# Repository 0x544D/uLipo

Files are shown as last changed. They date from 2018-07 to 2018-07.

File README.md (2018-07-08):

# uLipo
LiPo based universal Microcontroller board featuring an ATMega328p

# Features
* ATMega328p based microcontroller platform for various projects
* LiPo charging upto 500 mA/h using MCP73833
* Step-up voltage regulation LiPo voltage -> 5V
* USB-UART bridge for communication with PC over USB using COM port (CH340G)
* Arduino Nano compatible pinout

# Shields
* Shield Template can be used to create stackable shields.
* Shield for LED application available (WS2812B)

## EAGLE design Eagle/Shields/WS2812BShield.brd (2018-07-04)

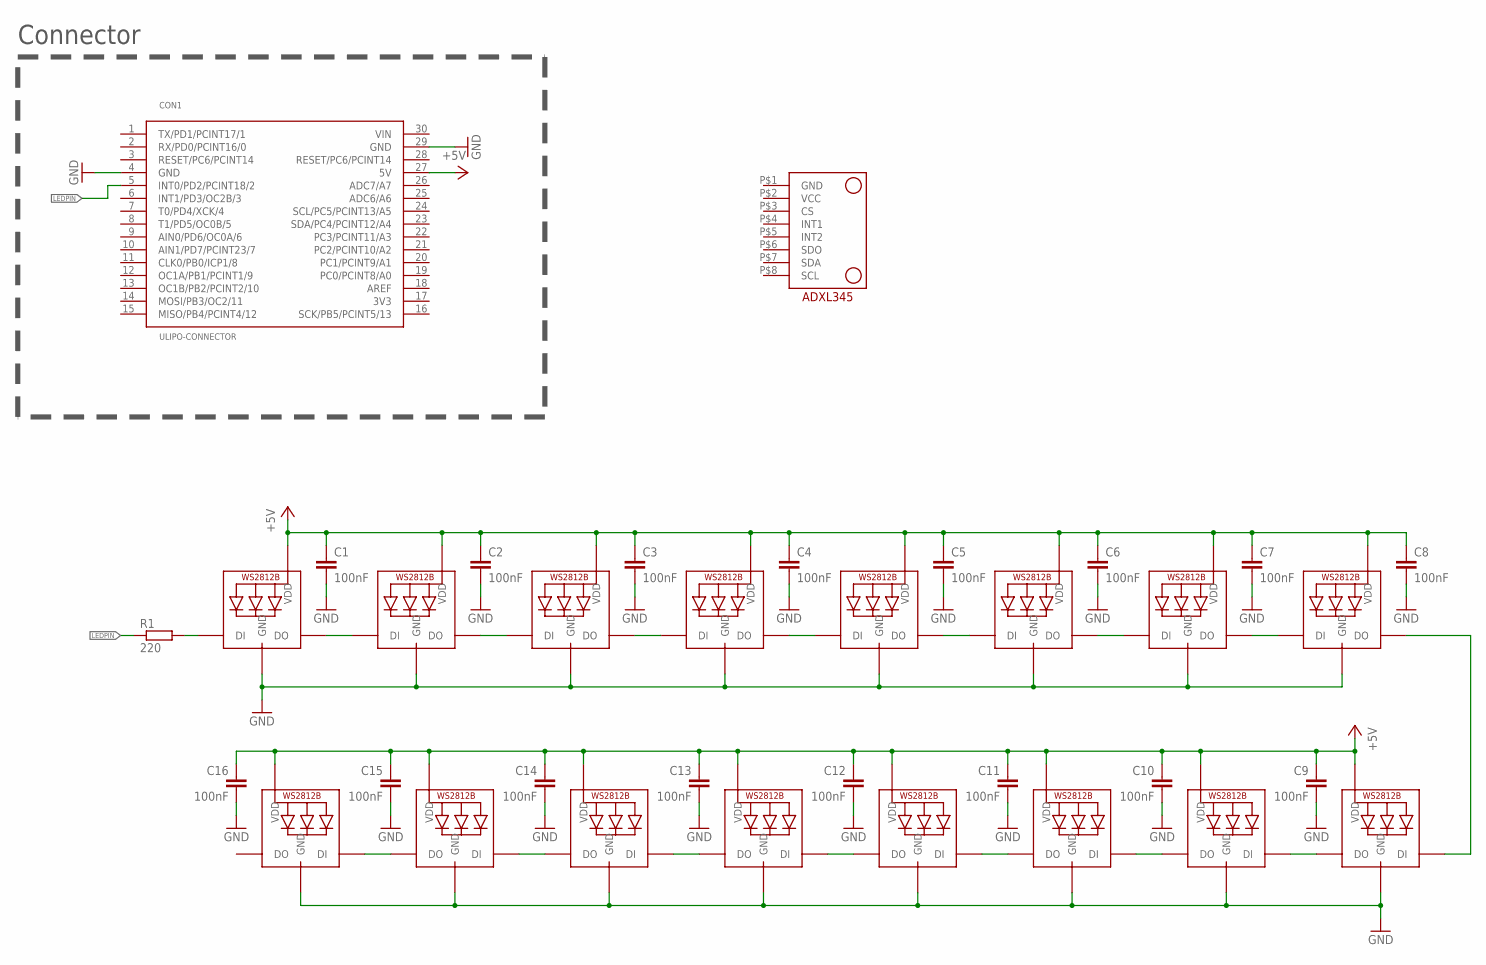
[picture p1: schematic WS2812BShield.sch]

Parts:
C1, C2, C3, C4, C5, C6, C7, C8, C9, C10, C11, C12, C13, C14, C15, C16: 100nF; C0603K
CON1: ULIPO-CONNECTOR
LED1, LED2, LED3, LED4, LED5, LED6, LED7, LED8, LED9, LED10, LED11, LED12, LED13, LED14, LED15, LED16: WS2812B5050; WS2812B
R1: 220; R0603
U$1: ADXL345

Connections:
+5V: C1.1, C2.1, C3.1, C4.1, C5.1, C6.1, C7.1, C8.1, C9.1, C10.1, C11.1, C12.1, C13.1, C14.1, C15.1, C16.1, CON1.27 (5V), LED1.1-VDD (VDD), LED2.1-VDD (VDD), LED3.1-VDD (VDD), LED4.1-VDD (VDD), LED5.1-VDD (VDD), LED6.1-VDD (VDD), LED7.1-VDD (VDD), LED8.1-VDD (VDD), LED9.1-VDD (VDD), LED10.1-VDD (VDD), LED11.1-VDD (VDD), LED12.1-VDD (VDD), LED13.1-VDD (VDD), LED14.1-VDD (VDD), LED15.1-VDD (VDD), LED16.1-VDD (VDD)
GND: C1.2, C2.2, C3.2, C4.2, C5.2, C6.2, C7.2, C8.2, C9.2, C10.2, C11.2, C12.2, C13.2, C14.2, C15.2, C16.2, CON1.4 (GND), CON1.29 (GND), LED1.3-GND (GND), LED2.3-GND (GND), LED3.3-GND (GND), LED4.3-GND (GND), LED5.3-GND (GND), LED6.3-GND (GND), LED7.3-GND (GND), LED8.3-GND (GND), LED9.3-GND (GND), LED10.3-GND (GND), LED11.3-GND (GND), LED12.3-GND (GND), LED13.3-GND (GND), LED14.3-GND (GND), LED15.3-GND (GND), LED16.3-GND (GND)
LEDPIN: CON1.5 (INT0/PD2/PCINT18/2), R1.1
unnamed: LED1.4-DIN (DI), R1.2
unnamed: LED1.2-DOUT (DO), LED2.4-DIN (DI)
unnamed: LED2.2-DOUT (DO), LED3.4-DIN (DI)
unnamed: LED3.2-DOUT (DO), LED4.4-DIN (DI)
unnamed: LED4.2-DOUT (DO), LED5.4-DIN (DI)
unnamed: LED5.2-DOUT (DO), LED6.4-DIN (DI)
unnamed: LED6.2-DOUT (DO), LED7.4-DIN (DI)
unnamed: LED7.2-DOUT (DO), LED8.4-DIN (DI)
unnamed: LED9.2-DOUT (DO), LED10.4-DIN (DI)
unnamed: LED10.2-DOUT (DO), LED11.4-DIN (DI)
unnamed: LED11.2-DOUT (DO), LED12.4-DIN (DI)
unnamed: LED12.2-DOUT (DO), LED13.4-DIN (DI)
unnamed: LED13.2-DOUT (DO), LED14.4-DIN (DI)
unnamed: LED14.2-DOUT (DO), LED15.4-DIN (DI)
unnamed: LED15.2-DOUT (DO), LED16.4-DIN (DI)
unnamed: LED8.2-DOUT (DO), LED9.4-DIN (DI)

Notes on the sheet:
Connector

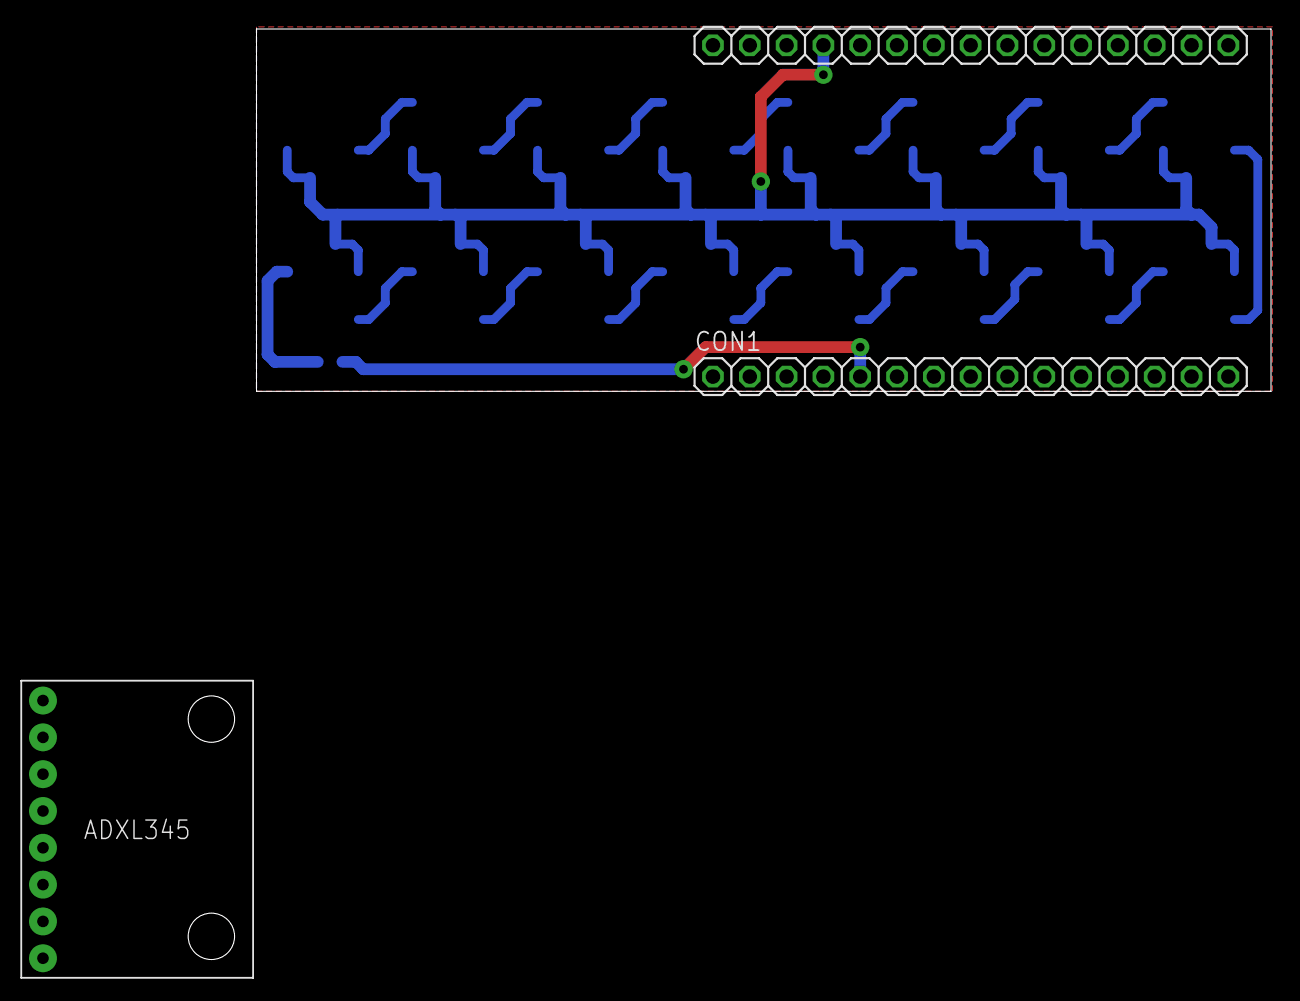
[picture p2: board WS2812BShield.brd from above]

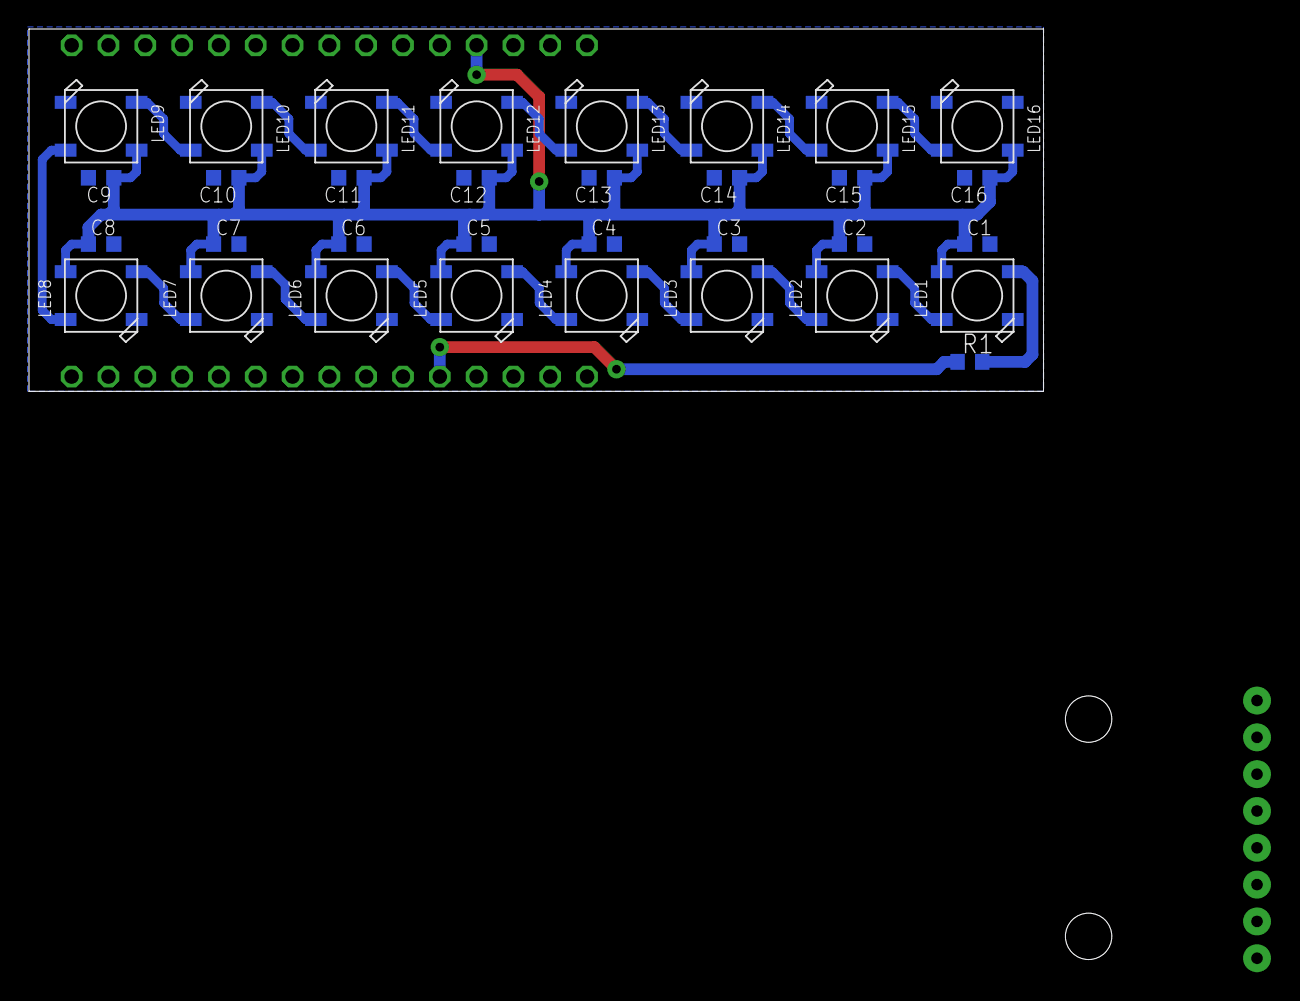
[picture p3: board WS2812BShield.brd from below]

Board: 2 copper layers, 70.0 x 25.0 mm, 35 parts (33 on the bottom side), 19 nets.

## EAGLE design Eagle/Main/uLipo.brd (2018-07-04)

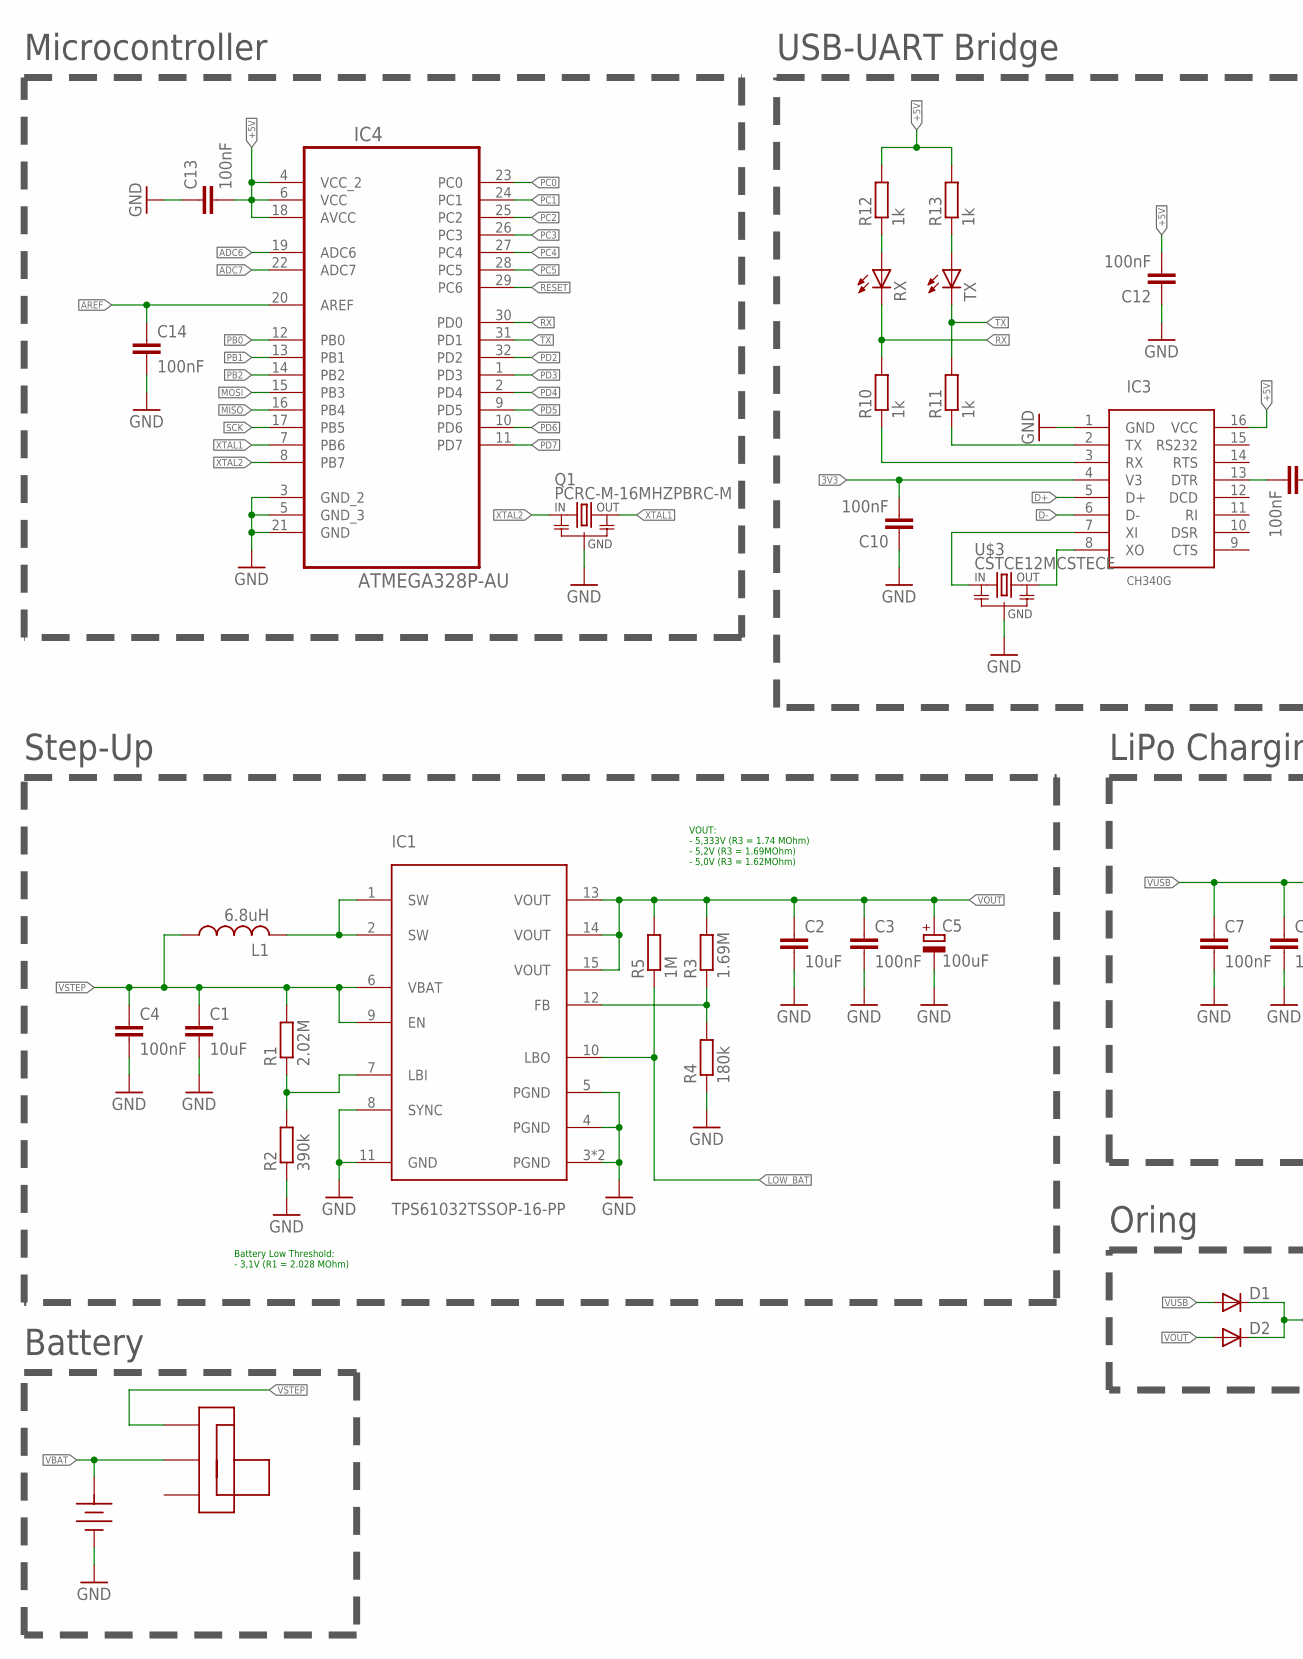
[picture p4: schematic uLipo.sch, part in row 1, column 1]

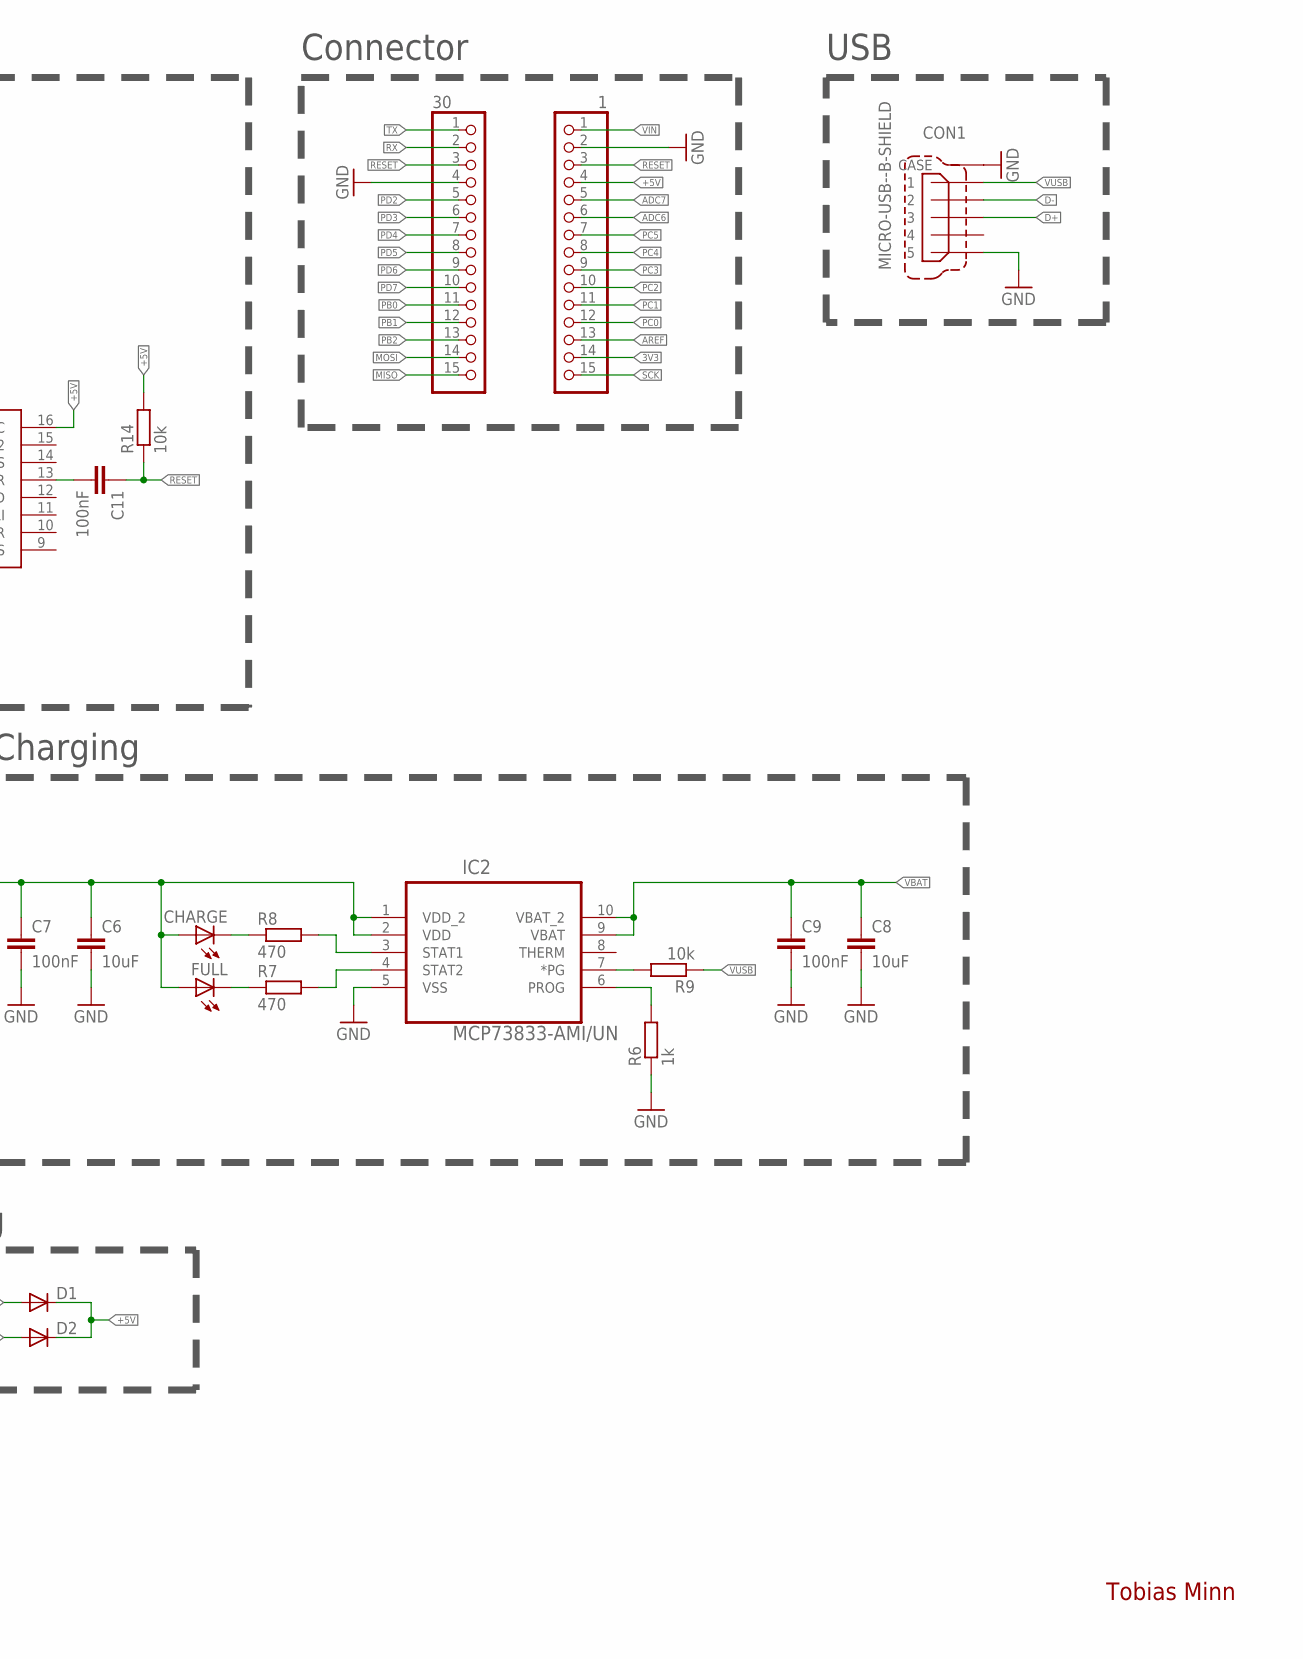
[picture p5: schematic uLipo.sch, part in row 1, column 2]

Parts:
1, 30: PINHD-1X15/OCT/BIG; 1X15/OCT/BIG
BAT: 18650BATTERY
C1, C2, C6, C8: 10uF; C0603K
C3, C4, C7, C9, C10, C11, C12, C13, C14: 100nF; C0603K
C5: 100uF; CT3528
CHARGE: LEDSML0603; SML0603
CON1: MICRO-USB--B-SHIELD; MOLEX_47346-0001
D1, D2: DIODE-SOD123; SOD123
FULL: LEDSML0603; SML0603
IC1: TPS61032TSSOP-16-PP; TSSOP-16-PP
IC2: MCP73833-AMI/UN; SOP50P490X110-10N
IC3: CH340G; SOIC16
IC4: ATMEGA328P-AU; QFP80P900X900X120-32N
L1: 6.8uH; MGV0603
Q1: PCRC-M-16MHZPBRC-M; PBRC-M
R1: 2.02M; R0603
R2: 390k; R0603
R3: 1.69M; R0603
R4: 180k; R0603
R5: 1M; R0603
R6, R10, R11, R12, R13: 1k; R0603
R7, R8: 470; R0603
R9, R14: 10k; R0603
RX: LEDCHIP-LED0603; CHIP-LED0603
TX: LEDCHIP-LED0603; CHIP-LED0603
U$2: SWITCH
U$3: CSTCE12MCSTECE; CSTCE12M

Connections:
3V3: 1.14, C10.2, IC3.4 (V3)
+5V: 1.4, C12.2, C13.2, D1.C, D2.C, IC3.16 (VCC), IC4.4 (VCC_2), IC4.6 (VCC), IC4.18 (AVCC), R12.2, R13.2, R14.2
ADC6: 1.6, IC4.19 (ADC6)
ADC7: 1.5, IC4.22 (ADC7)
AREF: 1.13, C14.1, IC4.20 (AREF)
D+: CON1.3, IC3.5 (D+)
D-: CON1.2, IC3.6 (D-)
GND: 1.2, 30.4, BAT.P$2 (P2), C1.2, C2.2, C3.2, C4.2, C5.-, C6.2, C7.2, C8.2, C9.2, C10.1, C12.1, C13.1, C14.2, CON1.5, CON1.M1 (CASE), CON1.M2 (CASE), CON1.M3 (CASE), CON1.M4 (CASE), CON1.M5 (CASE), CON1.M6 (CASE), IC1.3 (PGND), IC1.4 (PGND), IC1.5 (PGND), IC1.8 (SYNC), IC1.11 (GND), IC1.17 (PGND), IC2.5 (VSS), IC3.1 (GND), IC4.3 (GND_2), IC4.5 (GND_3), IC4.21 (GND), Q1.2 (GND), R2.1, R4.1, R6.1, U$3.2 (GND)
LOW_BAT: IC1.10 (LBO), R5.1
MISO: 30.15, IC4.16 (PB4)
MOSI: 30.14, IC4.15 (PB3)
unnamed: IC1.1 (SW), IC1.2 (SW), L1.P$2 (2)
unnamed: IC2.4 (STAT2), R7.2
unnamed: IC1.12 (FB), R3.1, R4.2
unnamed: IC2.3 (STAT1), R8.2
unnamed: IC1.7 (LBI), R1.1, R2.2
unnamed: CHARGE.C, R8.1
unnamed: FULL.C, R7.1
unnamed: IC2.7 (*PG), R9.2
unnamed: IC2.6 (PROG), R6.2
unnamed: IC3.2 (TX), R11.1
unnamed: IC3.3 (RX), R10.1
unnamed: R12.1, RX.A
unnamed: R13.1, TX.A
unnamed: IC3.7 (XI), U$3.1 (IN)
unnamed: IC3.8 (XO), U$3.3 (OUT)
unnamed: C11.2, IC3.13 (DTR)
PB0: 30.11, IC4.12 (PB0)
PB1: 30.12, IC4.13 (PB1)
PB2: 30.13, IC4.14 (PB2)
PC0: 1.12, IC4.23 (PC0)
PC1: 1.11, IC4.24 (PC1)
PC2: 1.10, IC4.25 (PC2)
PC3: 1.9, IC4.26 (PC3)
PC4: 1.8, IC4.27 (PC4)
PC5: 1.7, IC4.28 (PC5)
PD2: 30.5, IC4.32 (PD2)
PD3: 30.6, IC4.1 (PD3)
PD4: 30.7, IC4.2 (PD4)
PD5: 30.8, IC4.9 (PD5)
PD6: 30.9, IC4.10 (PD6)
PD7: 30.10, IC4.11 (PD7)
RESET: 1.3, 30.3, C11.1, IC4.29 (PC6), R14.1
RX: 30.2, IC4.30 (PD0), R10.2, RX.C
SCK: 1.15, IC4.17 (PB5)
TX: 30.1, IC4.31 (PD1), R11.2, TX.C
VBAT: BAT.P$1 (P1), C8.1, C9.1, IC2.9 (VBAT), IC2.10 (VBAT_2), U$2.P$1
VIN: 1.1
VOUT: C2.1, C3.1, C5.+, D2.A, IC1.13 (VOUT), IC1.14 (VOUT), IC1.15 (VOUT), R3.2, R5.2
VSTEP: C1.1, C4.1, IC1.6 (VBAT), IC1.9 (EN), L1.P$1 (1), R1.2, U$2.P$2
VUSB: C6.1, C7.1, CHARGE.A, CON1.1, D1.A, FULL.A, IC2.1 (VDD_2), IC2.2 (VDD), R9.1
XTAL1: IC4.7 (PB6), Q1.3 (OUT)
XTAL2: IC4.8 (PB7), Q1.1 (IN)

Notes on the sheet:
USB-UART Bridge
Microcontroller
Connector
VOUT: - 5,333V (R3 = 1.74 MOhm) - 5,2V (R3 = 1.69MOhm) - 5,0V (R3 = 1.62MOhm)
Battery Low Threshold: - 3,1V (R1 = 2.028 MOhm)
Step-Up
LiPo Charging
Oring
USB
Battery
Tobias Minn

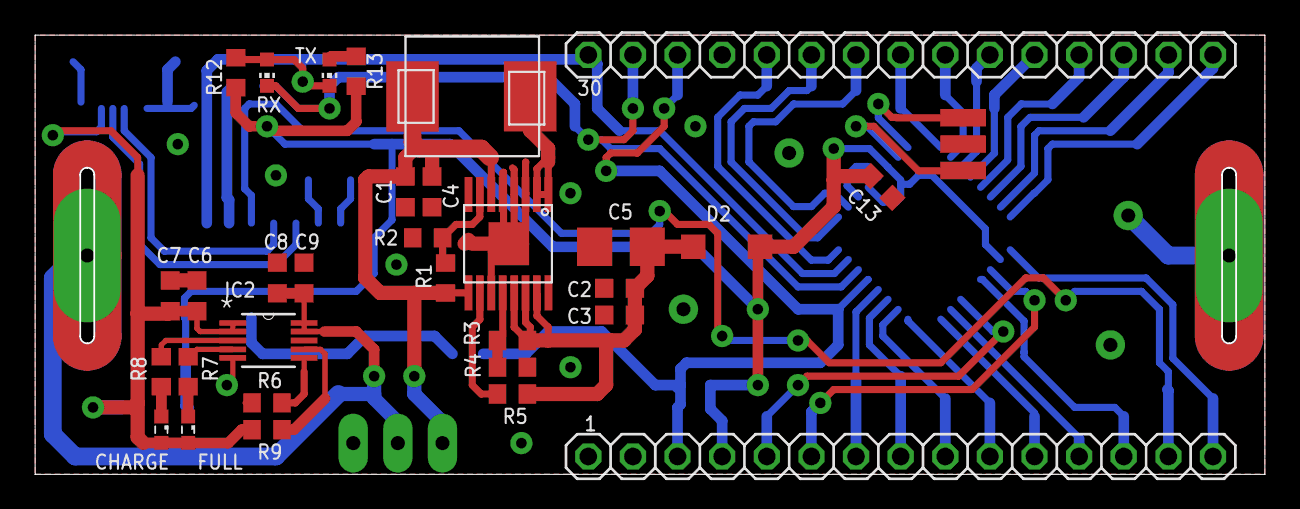
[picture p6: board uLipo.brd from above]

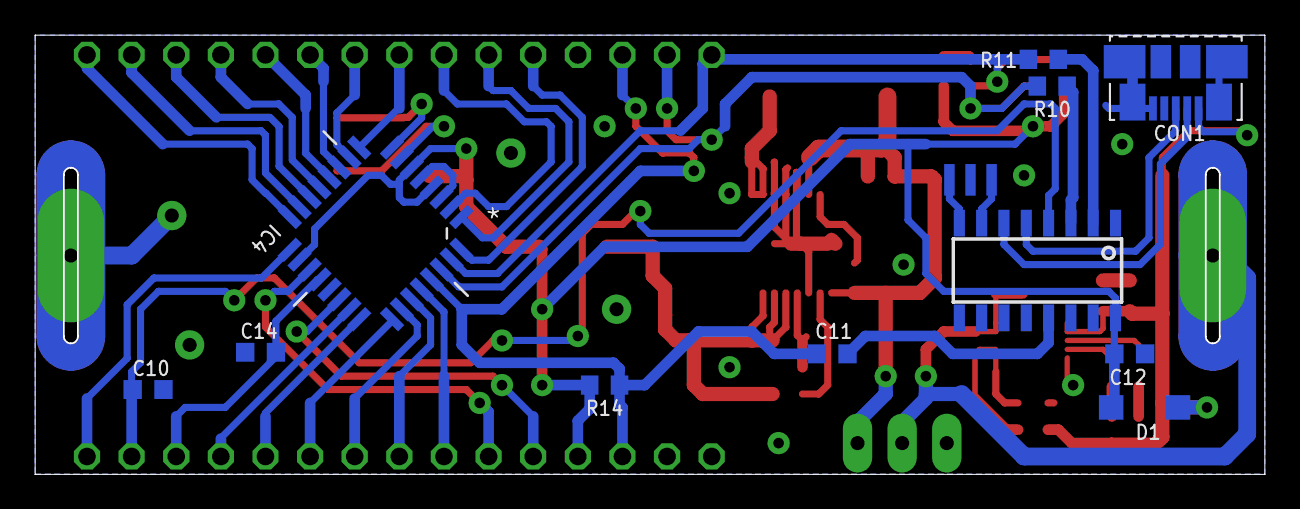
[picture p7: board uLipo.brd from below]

Board: 2 copper layers, 70.0 x 25.0 mm, 46 parts (12 on the bottom side), 52 nets.
